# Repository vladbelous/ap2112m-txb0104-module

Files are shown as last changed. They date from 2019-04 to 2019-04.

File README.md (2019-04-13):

# AP2112M 3.3V-regulator with TXB0104 logic level shifter

Simple module for AP2112M 3.3V regulator (5V -> 3.3V), combined with TXB0104-based logic level shifter.

AP2112M is 8-SOIC (3.90mm width) and TXB0104 is 14-SOIC (3.90mm width).

Minimal components include 4 capacitors (2 x 1uF in 1206, and 2 x 0.1uF in 805), and one pull-down resistor (in 805).

Optional:
* ON/OFF SPDT switch (if not placed, solder a wire between EN and 5V, i.e. between pins under "ON" text)
* Micro USB (type B) connector. Use 4-leg footprint (available on various different sites)
* If Micro USB is used, place either D1 (for extra safety), or solder JP1 jumper (e.g. 0R in 805)
* JST PH (2.0mm) side conentor - may be useful for powering boards with such battery connector.

A version of this PCB (with round holes for micro USB) can be [ordered on PCBs.io](https://PCBs.io/share/rb7jV).

Designed with [KiCad 5](www.kicad-pcb.org).

## Schematic:
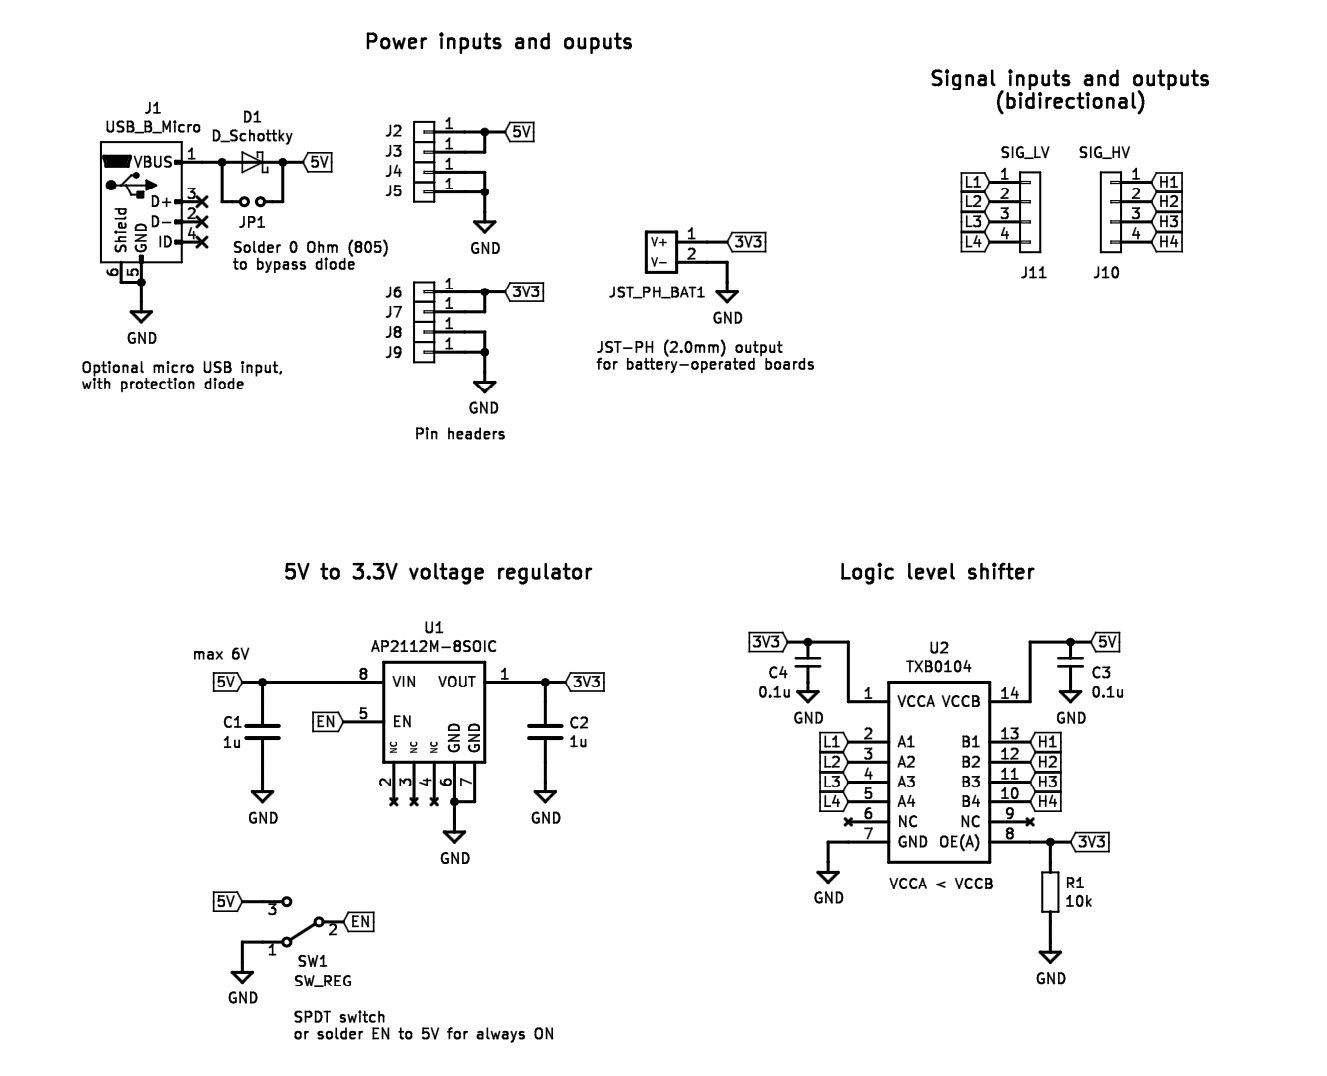
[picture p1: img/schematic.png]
schematic


## Layout:
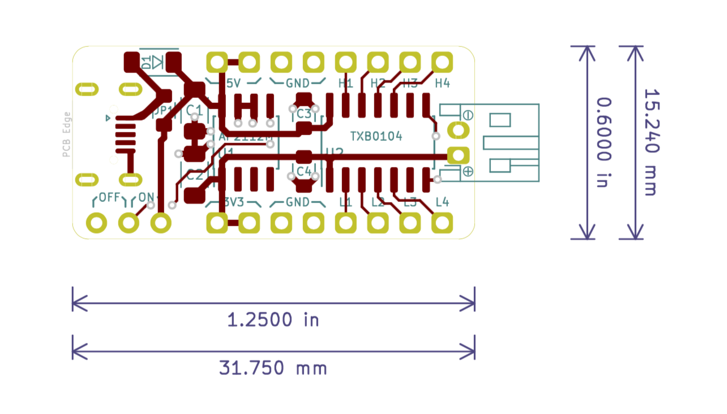
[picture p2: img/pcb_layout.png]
layout


## Render (PCBs.io):
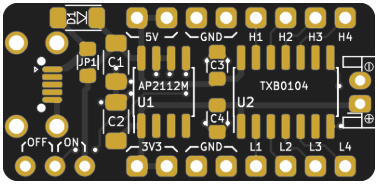
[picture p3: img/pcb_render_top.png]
render top

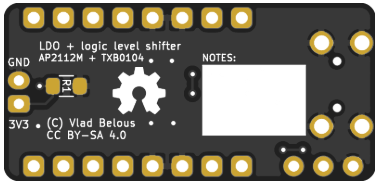
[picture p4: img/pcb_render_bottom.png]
render bottom


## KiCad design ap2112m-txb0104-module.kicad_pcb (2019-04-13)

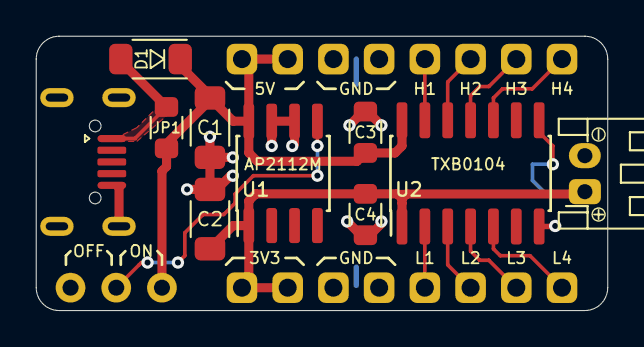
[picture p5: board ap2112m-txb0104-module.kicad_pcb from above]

Board: 2 copper layers, 31.8 x 15.2 mm, 22 parts (1 on the bottom side), 13 nets.

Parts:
C1, C2: 1u; 1206_HS
C3, C4: 0.1u; 0805_HS
D1: D_Schottky; 1206_Diode_HS
J1: USB_B_Micro; USB-micro-B_4-legs_Banggood
J2, J3: VIN_HV; Pin_Header_Straight_1x01_Pitch2.54mm
J4, J5, J8, J9: GND; Pin_Header_Straight_1x01_Pitch2.54mm
J6, J7: VOUT_LV; Pin_Header_Straight_1x01_Pitch2.54mm
J10: SIG_HV; Pin_Header_Straight_1x04_Pitch2.54mm
J11: SIG_LV; Pin_Header_Straight_1x04_Pitch2.54mm
JP1: 0 Ohm; 0805_HS
JST_PH_BAT1: JST_PH_BAT; JST_PH_S2B-PH-K_02x2.00mm_Angled_WiderHole
R1: 10k; 0805_HS
SW1: SW_REG; Conn_01x03_small
U1: AP2112M-8SOIC; SOIC-8_3.9x4.9mm_Pitch1.27mm_HS
U2: TXB0104; SOIC-14_3.9x8.7mm_Pitch1.27mm_HS

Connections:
3V3: C2.1, C4.1, J6.1, J7.1, JST_PH_BAT1.1, R1.1, U1.1, U2.1, U2.8
5V: C1.1, C3.1, D1.1, J2.1, J3.1, JP1.2, SW1.3, U1.8, U2.14
EN: SW1.2, U1.5
GND: C1.2, C2.2, C3.2, C4.2, J1.5, J1.6, J4.1, J5.1, J8.1, J9.1, JST_PH_BAT1.2, R1.2, SW1.1, U1.6, U1.7, U2.7
H1: J10.1, U2.13
H2: J10.2, U2.12
H3: J10.3, U2.11
H4: J10.4, U2.10
L1: J11.1, U2.2
L2: J11.2, U2.3
L3: J11.3, U2.4
L4: J11.4, U2.5
unnamed: D1.2, J1.1, JP1.1

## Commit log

2019-04-11 Complete schematic
    [ap2112m-txb0104-module.sch]
2019-04-12 Create/assign footprints, export netlist
    [ap2112m-txb0104-module.sch]
2019-04-12 Component placement, outline, no routing
    [ap2112m-txb0104-module.kicad_pcb]
2019-04-13 Finish routing and silkscreen
    [ap2112m-txb0104-module.kicad_pcb]
2019-04-13 Add images and README
    [ap2112m-txb0104-module.sch]
2019-04-13 Update README, add renders, add gerbers for round-hole variant
    [ap2112m-txb0104-module-B_Cu.gbl, ap2112m-txb0104-module-B_Mask.gbs, ap2112m-txb0104-module-B_SilkS.gbo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]

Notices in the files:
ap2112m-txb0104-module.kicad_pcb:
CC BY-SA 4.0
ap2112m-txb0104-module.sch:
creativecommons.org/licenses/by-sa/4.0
